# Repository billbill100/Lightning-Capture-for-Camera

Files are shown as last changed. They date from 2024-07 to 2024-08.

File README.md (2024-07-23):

# Lightning-Capture-for-Camera
Build a cheap device for your camera, to automatically photograph lightning as it happens.

Based on Arduino (but using a faster ESP32 processor), this clever device allows your camera to wait in standby, watching for lightning and take a photo the instant lightning is seen.

A dslr or mirrorless camera with a cable release socket will be required.

Using a battery powered processor, complete with built in-charger and off-the-shelf modules, the device can be quickly and easily built. There is no need to make or order complicated circuit boards (pcb).

A little soldering skill is required, as is a bit of computer skill to load the firmware onto the device, but there are how-to guides for each step and a user forum on Photrio.

There are two versions that can be built.
The full version includes an Oled display, with parameters that can be changed.
A basic model, with minimam components, that just works, using the default parameters.

Now the caveat. The device has been built & tested and it works great indoors. However there has yet to be thunderstorm to test it in the real world. As soon as a suitable storm blows through, I will be running outsideto fully test the device.

This is a new project, so documentation may change over the coming weeks.

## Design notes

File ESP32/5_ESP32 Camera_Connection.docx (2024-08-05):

GitHub repository where all documentation & code can be found. billbill100 (github.com) (https://github.com/billbill100)

Trigger Trap Timer & Lightning Capture

Camera Connections V1.1 18/07/2024

The opto-isolator board provides total electrical separation between the camera and the timer. One of the chips on the board is an ‘opto-isolator’. On one side is an LED, which lights when controlled by the ESP32. On the other side is a photo-resister., which sees this light & responds in kind. There is no electrical connection, the only thing passing across is light. This light is used to control the other side of the board, which connects to the camera.


Purchase the correct camera shutter release cable for your camera, to 3.5mm socket.

Canon use two different connectors, depending on the camera. A 2.5mm socket or bespoke Canon connector.

Nikon use three different camera connectors.

Canon & Nikon are the simplest of cables and a pre-made shutter release cable should be wired as such and should work without modification.

Some manufacturers use just two wires, but with added resisters, Fuji & Panasonic, for example. This makes the cable a little more complicated. Having not used such a camera or cable, I cannot say if pre-made cables have the additional resistors built in or not. For these cameras, some experimentation will be required & the use of a multimeter to test the cables.


To connect to the Trigger/ Lightning box 3.5mm jack plug,
Common Outer - Black
Focus to collar - Yellow
Shutter to Tip - Green

Below are links to useful web sites showing the connectors & pin-outs.

www.doc-diy.net :: camera remote release pinout list (https://www.doc-diy.net/photo/remote_pinout/)

DIY - Release Cable for Canon DSLRs (diyphotography.net) (https://www.diyphotography.net/release_cable_for_canon_dslr/)

Canon N3 Connector Pinout and Wiring : Martin Pot - Photography Blog (martybugs.net) (https://martybugs.net/blog/blog.cgi/gear/CanonN3Connector.html)

Panasonic Shutter Release Cable for Arduino Camera Control and Timelapse Ep 22 (youtube.com) (https://www.youtube.com/watch?v=_ZOJiIvAwBE&ab_channel=SunPixelVideo)

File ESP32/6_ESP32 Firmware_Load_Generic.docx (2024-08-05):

GitHub repository where all documentation & code can be found. billbill100 (github.com) (https://github.com/billbill100)

ESP32 generic firmware load. V1.0 23/07/2024

Download the code from the github page.
Go to the github page following the link above and then select the required project.
Click on the green <>Code button, which will allow you to download all of the files as a zip file.
Unzip (extract) the downloaded files.

Download the Flashing software.

A program called Flash Download Tool is required. It is included on the Github page, or can be downloaded from
Tools | Espressif Systems (https://www.espressif.com/en/support/download/other-tools)

Unzip (extract) the folder and put the files somewhere suitable on the computer. The software is stand-alone and does not need to be installed.

Checking the ESP32 USB driver.

The USB driver should have been installed, following the driver installation guide. To confirm, after connecting the ESP32 board, press Windows key + x and select Device Manager. Look for the COM ports and expand. The ESP module should be seen, as in this example on COM port 6, showing the CP2102 driver.

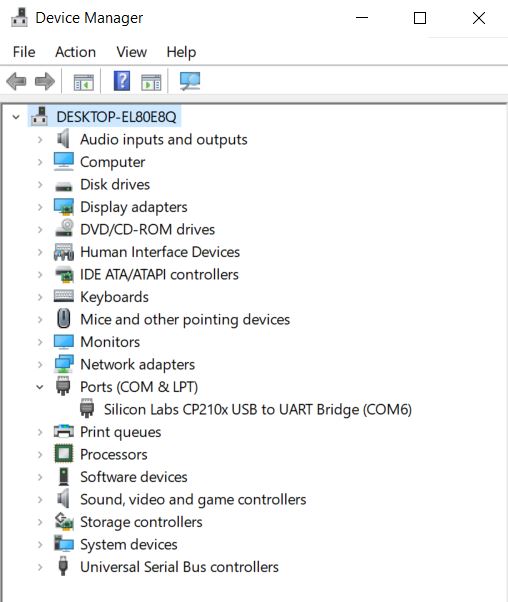
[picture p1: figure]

If the driver is missing, as shown on the screen below (Yellow Triangle) refer to the document Installing CP2102 Driver. Found in the github repository.

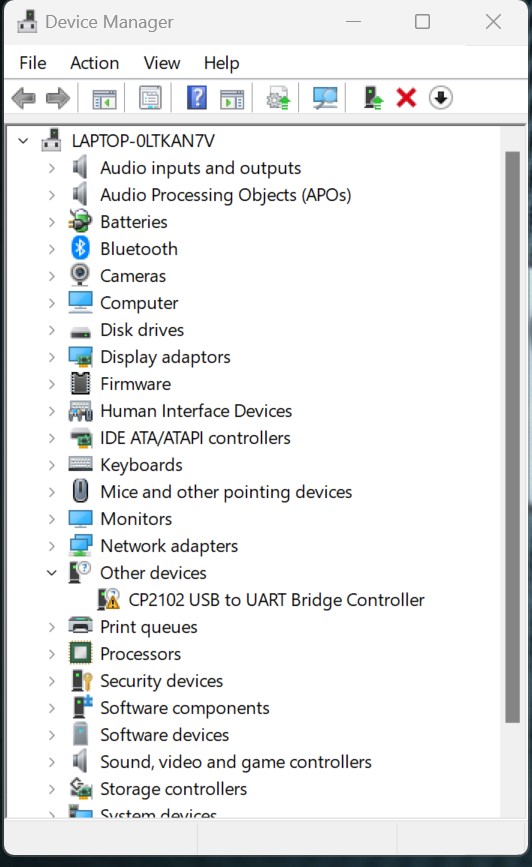
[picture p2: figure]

Flash the firmware to ESP32

Find the folder where the Flash Download Tool files were extracted to.

Launch the Flash Download Tool by double clicking on ‘flash_download_tool_3.9.5.exe’

Select ‘ESP32 from the drop-down box, as shown in the screenshot below and click ok.

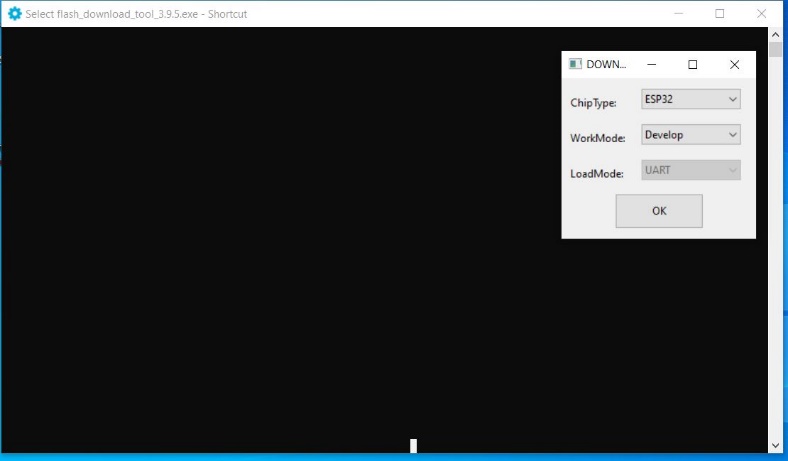
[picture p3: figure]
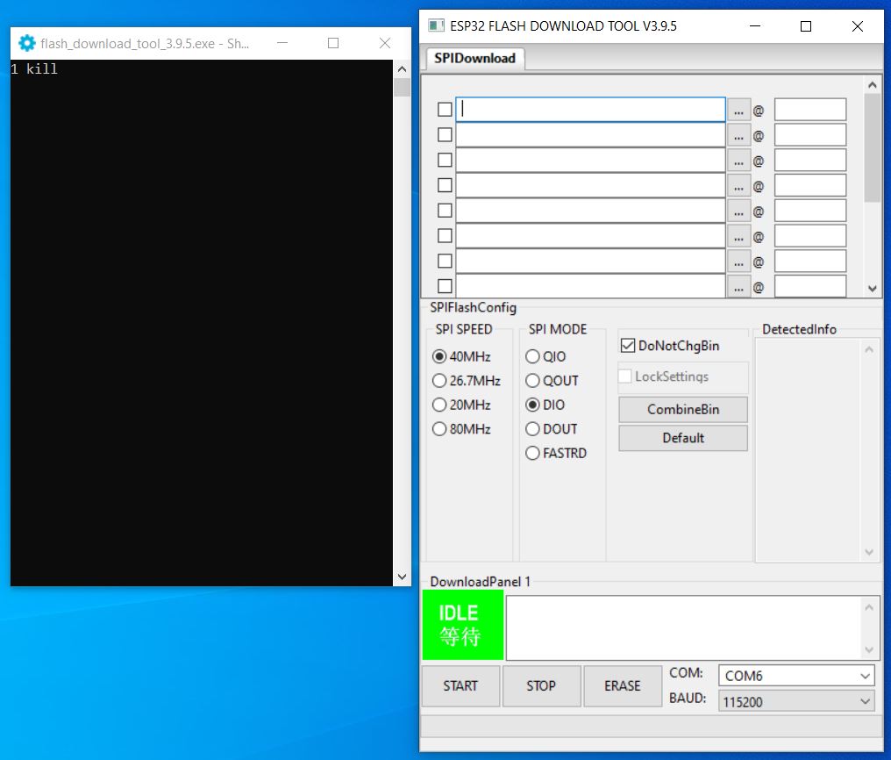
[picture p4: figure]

A screen like the below will appear and must now be populated. (The two windows can be moved as required)

Populate the values as follows

1) Click the three dots next to the top box, navigate to, and select the downloaded filename_x_x_x_x.ino.bootloader.bin. file. Do the same on the second line, selecting filename_x_x_x_.ino.partitions.bin and again for the third line filename_x_x_x_x.ino.bin If the files are selected correctly, the black window (5) will show each file name

(ensure the files are in the correct order)

2) Type 0x1000 into the top box, 0x8000 into the second and 0x10000 into the third.
3) Tick the three boxes next to the file names
4) Select the correct COM port from the drop-down box

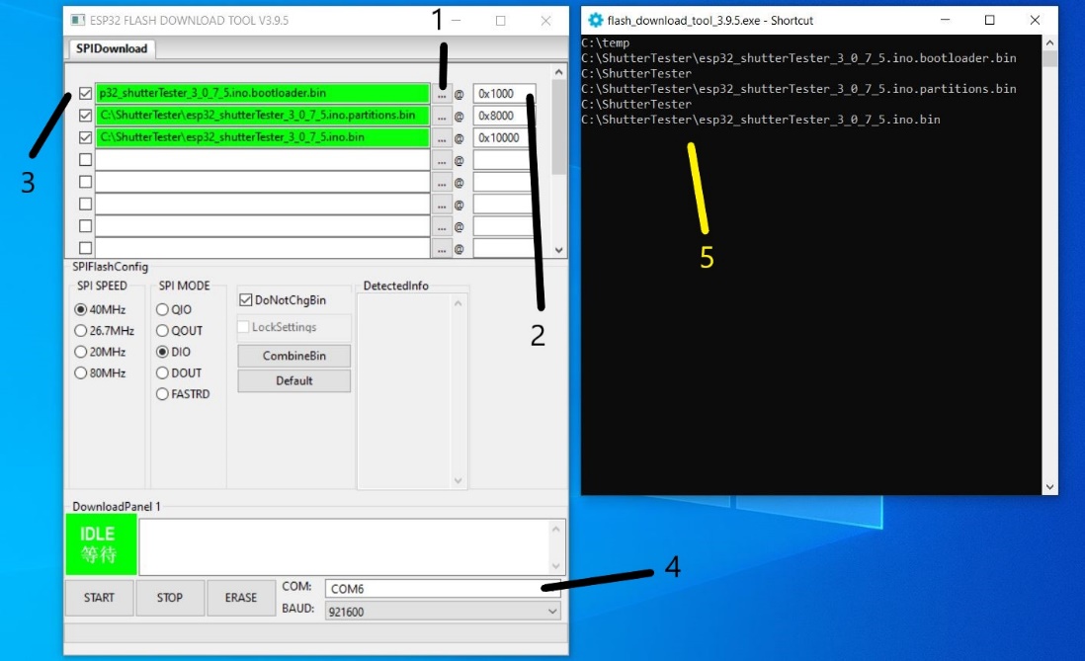
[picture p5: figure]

The file names and number boxes will be green, if the Flash Download Tool as found the files & is happy with the values.

Now press ‘Start’ at the bottom left of the box. The green ‘IDLE’ box will change to ‘SYNC’

A line of dots will appear on the black screen, Only if using the nodeMcu-32 board, press the Boot button on the ESP32 board for 3 seconds and then release. (The Lolinn board, as used in Lightning_Detector & Developing_Timer does not have the boot button)

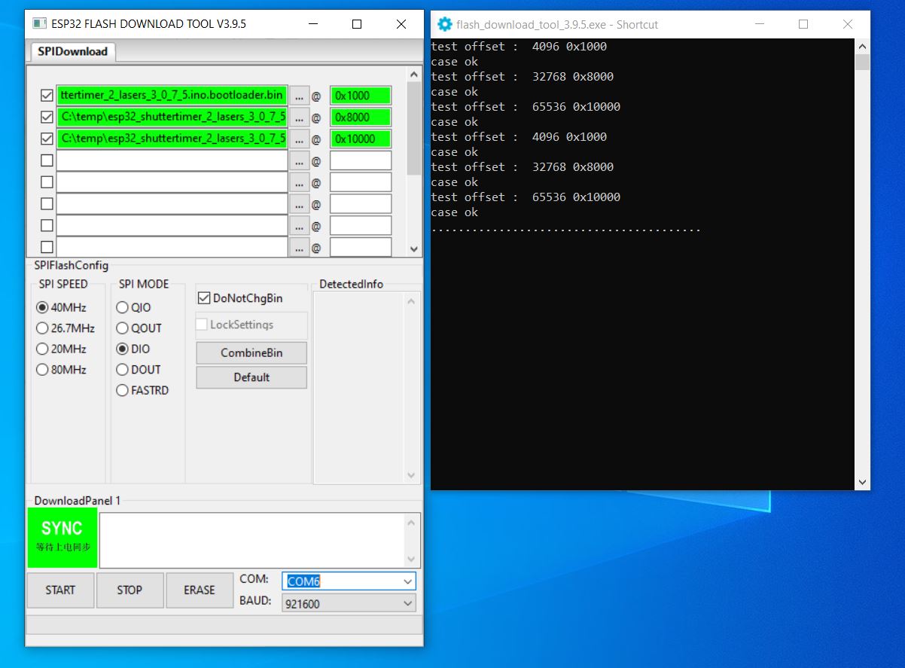
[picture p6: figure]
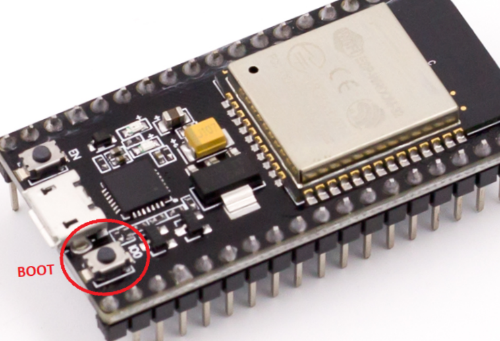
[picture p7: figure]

If successful, a screen, as below, will be seen. The Black screen will show the flashing to the device. A green progress bar blue box will appear in the other screen, then the green start button will change to a blue ‘FINISH’

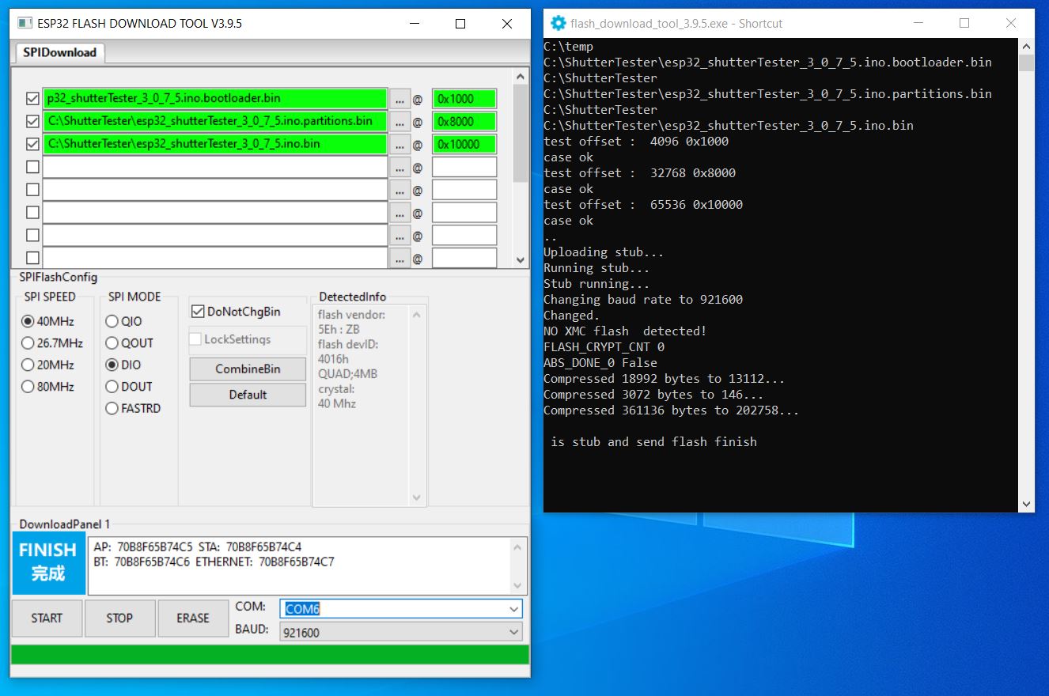
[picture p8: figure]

Note:- the flashed code will not start running until the Reset button has been pushed on the ESP32 board.

If problems occur, check the following:-

Remove & insert the USB cable into the computer. Windows, by default will make a sound indicating a USB device has been connected.

Open Device Manager and check the ESP32 board is shown. Removing & re-inserting the USB cable will make the ESP32 disappear & re-appear.

Ensure there is no yellow warning triangle by the COM port in Device Manager, indicating the device driver is not loaded.

Try changing the baud value to 115200 and try again.

If any of the file names or numbers did not turn green as they were selected & the black window report ‘case ok’, then there is an issue with the downloaded flash files, or the stored location on the computer.

Note:- this is a generic guide to loading firmware for the billblill projects.
The actual filenames will be different than those shown in the screen shots, but ensure the second part of the three file names, bootloader.bin partitions.bin and ino.bin are in the correct order as shown in the screenshots.

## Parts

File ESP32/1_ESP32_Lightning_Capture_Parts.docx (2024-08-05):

I would really be grateful if you start to build the Lightning Capture Device, that you go to the Photrio thread and say hi. Also please post photos of your completed project.
Please refer to the Photrio thread for further build help
Lightning Capture Device - Cheap - Simple & it works (photrio.com) (https://www.photrio.com/forum/threads/capture-lightning-device-cheap-simple-it-works.207958/)

GitHub repository where all documentation & code can be found. billbill100 (github.com) (https://github.com/billbill100)

Please refer to the Photrio thread for further build help

ESP32 Lightning Capture Parts V1.0 28 06 2024

Below are links to the parts required to make the ESP32 Lightning Capture device.

Links are valid now, but of course could become dead in the future.

Links are a guide only. Use a supplier in, or will post to your country.

Ordering from China either from eBay sellers or AliExpress, the parts will be much cheaper.

Note, often if buying from AliExpress, there is a free express shipping option, if buying parts over a set value.

One of two versions can be built, either fully featured with Oled and controls or a minimal version, The Schematic diagrams show the two versions.

ESP32 Lolin Wemos board

LOLIN D32 V1.0.0 - wifi+bluetooth board based ESP-32 esp32 ESP-WROOM-32 4MB FLASH Arduino MicroPython Compatible - AliExpress 502 (https://vi.aliexpress.com/item/1005006246561853.html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)

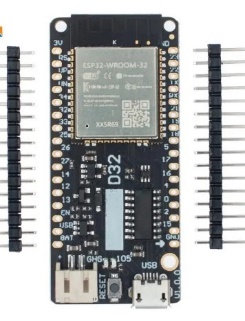
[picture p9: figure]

ESP32 prototype/breakout board (38 pin screw-terminal version)

New edition ESP32 Breakout Board for ESP32 WiFi Bluetooth Development Board NodeMCU-32S Lua 38Pin GPIO 1 into 2 Expansion Board - AliExpress 502 (https://vi.aliexpress.com/item/1005006100537758.html)

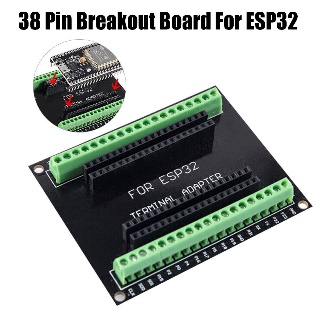
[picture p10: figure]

Dupont wires.

Get male to female ones if using the screw terminal prototype board.

It is suggested that two packs of 20cm and
two packs of 10cm wires are purchased.
This will allow for the exra Red & Black wires required.

Additionally a pack of 10cm male-male makes wiring to the opto-board easier. Alternate is to cut the F end from one Green, Yellow and Black wire.

Dupont Line 10cm 20cm Dupont Cables Male To Male Female To Female Male To FeMale Jumper Wire, for Arduino DIY Electronics KIT - AliExpress (https://www.aliexpress.com/item/1005006263457745.html?scm_id=1007.40050.354490.0&scm-url=1007.40050.354490.0)

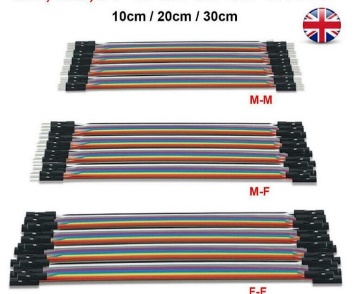
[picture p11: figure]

Rotary Encoder.
Ensure you purchase the one with blue pcb.

Rotating Potentiometer Knob Cap Digital Control Module Rotary Encoder Controller Switch 5V Diy Kit EC11 For Arduino PCB Board - AliExpress (https://www.aliexpress.com/item/1005006332290643.html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)

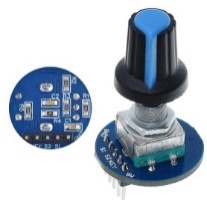
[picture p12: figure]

Project Box.
There are all sorts of shapes & sizes of project boxes. The 158 x 90 x 60 is a good size if using the breakout board.

Black Box Outdoor Waterproof Case Plastic Box Electronic Project Case Instrument Waterproof Junction Box Housing - AliExpress (https://www.aliexpress.com/item/1005005622148025.html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)

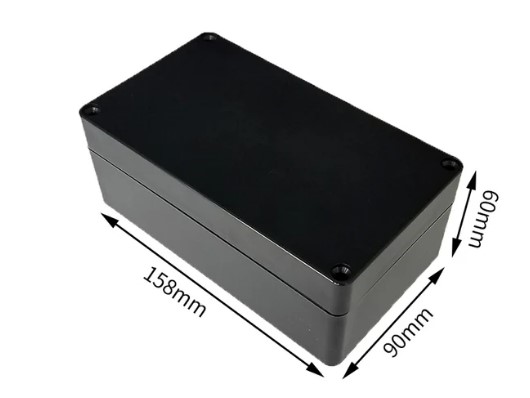
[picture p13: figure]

Oled screen
1.3” SH110X display

1.3" OLED module white/Blue color 128X64 1.3 inch OLED LCD LED Display Module 1.3" IIC I2C Communicate for arduino - AliExpress 502 (https://vi.aliexpress.com/item/1005006115101785.html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)

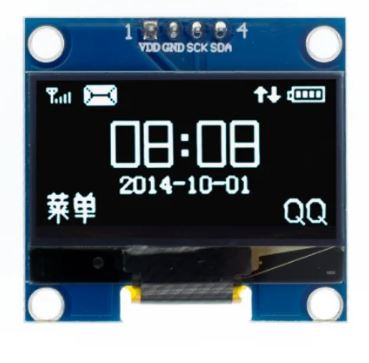
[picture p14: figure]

Opto isolation board
Two of these boards are required. Ensure you select the 3V-5V version when ordering.
Note:- The different versions seem to have got mixed up in china, so be prepared to change the resister on the board. Details in the documents.

1 Channel Way Optocoupler Isolation Module PC817 EL817 3V-5V 12V 24V Photoelectric Isolator Rail Holder PLC Drive Motor Board - AliExpress 502 (https://vi.aliexpress.com/item/1005003744306262.html)

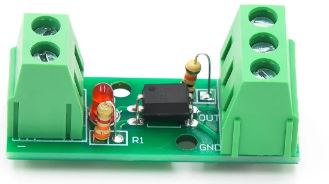
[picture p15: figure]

Resisters 27 Ohm
The resister on the opto board is too high for reliable working at 3 volts. It has also been found that the board sent, even if ordering the 3-5V version (which should have a 100 Ohm resister) may have a resister for working at 12 or 24 volts.
Simple solution is to replace it with a 27 Ohm resister to give correct operation at 3.3 volts.
100PCS Metal Film Resistor 1/4W 1% 100R 220R 1K 1.5K 2.2K 4.7K 10K 22K 47K 100K 100 220 1K5 2K2 4K7 Ohm Resistance 1R~22M - AliExpress 502 (https://vi.aliexpress.com/item/1005006427040577.html?mp=1)

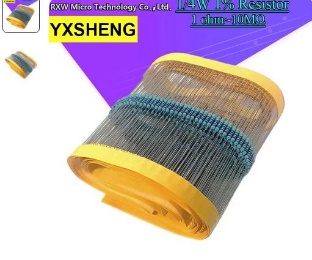
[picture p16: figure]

PCB mounting support (Optional).
20mm M3 & 10MM M3

The PCB in the prototype was mounted using wooden blocks. Whilst this does work, a neater solution is to use mounting spares designed for the purpose. 20mm for the breakout board & 10mm for the opto-isolator.

M2 M2.5 M3 M4 Nylon Motherboard Standoff PCB Support Circuit Board Column Rack Pillars Spacer Plastic Hex Screw Bolt and Nut Set - AliExpress 13 (https://vi.aliexpress.com/item/1005006038666758.html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)

Shutter Release Cable.
Get the correct one for your camera. An alternate is to buy a complete release & cut the button unit off.

2.5mm / 3.5mm Remote Shutter Release Cable Connecting Cord for Canon DSLR Camera As 3C C3 N3 Cable A as the cable of RS-80N3 - AliExpress 44 (https://vi.aliexpress.com/item/32851067494.html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)

2.5mm 3.5mm Remote Shutter Release Cable Connecting Cord for Nikon D850 D810 D700 D800 D300S D300 D4 D3X D2 As 1N N1 DC0 Cable B - AliExpress 44 (https://vi.aliexpress.com/item/32849320165.html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)

2.5 3.5 to Multi USB Remote Shutter Release Connecting Cable for Sony A7 A7S A7R II III IV V A6600 A6000 RX100 V as S2 Cable F2 - AliExpress (https://vi.aliexpress.com/item/32851067485.html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)

On/Off switch
There are hundreds of different types, pick one you like. Ensure it is ON/OFF and not momentary.

Push Button Switch Arduino|12mm Momentary Push Button Switches 3a 125vac 1.5a 250vac - 6pcs Set (aliexpress.com) (https://vi.aliexpress.com/item/4000164264475.html?mp=1)

Button

There are hundreds of different types, pick one you like. Ensure it is momentary.

(pre-soldered)

DaierTek 5PCS 12mm Momentary Push Button Switch On Off Mini Round Switch Waterproof PBS-33B 3A 125V AC with Pre-soldered Wire - AliExpress (https://www.aliexpress.com/item/1005005789195514.html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)


(require soldering)

6piece Mini 12mm Waterproof Momentary On/off Push Button Round Switch Pbs-33b Kit White Black Red Yellow Blue Green - AliExpress (https://www.aliexpress.com/item/1005006228814305.html)


Traffic Light LED (Optional)
These have built in resisters, thus simplifying use.

Mini 5V Traffic Light LED Display Module for Arduino Red Yellow Green 5mm LED RGB -Traffic Light for Traffic Light System Model - AliExpress 502 (https://vi.aliexpress.com/item/1005005568479247.html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)


Type C USB to Micro Adaptor (Optional)
The USB port will be recessed in the project box making connection a little fiddly. An adaptor or ‘port saver’ can be used to bring it outside of the box


Li-Po Battery (Optional, only for use with Lolin D32 board) With JST PH2.0 connector.
The prototype was built using the 1000mAh battery. A 2000mAh or 2500mAh battery will also work well. If using a different battery to the ones specified below, ensure they have the little pcb at the top, which gives under-voltage & over-current protection.
Note:- if ordering from China, delivery time maybe long as they are sent via ship, not air. Consider ordering from a supplier with stock in your country via Amazon or Ebay.

3.7V 1000mAh 3.7Wh Rechargeable Polymer Li Lithium Battery 523450 Lipo JST 2pin 1.5 Connector For Game Player LED GPS Car Camera - AliExpress 44 (https://vi.aliexpress.com/item/1005007364065757.html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)

3.7V 103450 2500mAh Lipo Polymer Lithium Rechargeable Battery 103450 battery For GPS navigator MP5 Speaker headset camera e-book - AliExpress 44 (https://vi.aliexpress.com/item/1005006274137007.html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)


Red & Black Pins require removal from plastic housing and swapping round.

Caution – There is no standard for the polarity of the battery connector. Check and double check the red & black wires are the correct way round on the battery connector, to match the Lolin processor board. If they are not, carefully lift the plastic locking tab on the connector, securing the pin & slide out. Do this for both pins, taking care not to let them touch. Then re-insert the correct way round. The batteries specified above have the connector pins the wrong way round and will need to be swapped.

Battery cable. (Optional)
Allows the battery wires to be easily extended without cutting..

2/5/10/20Pair Micro PH2 JST PH 2.0 PH2.0 2Pin Male Female Plug Jack Connector With Wire Cables 200mm - AliExpress 13 (https://vi.aliexpress.com/item/1005006623049916.html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)


Choc-block (Optional)
There are many 3V & 0V wires to be connected into a single terminal on the breakout board. A choc-bloc can be used to group all of the wires together & then just one wire from here to the breakout board.

Alternates are to solder them together, or use a joining block similar to the below,

10-75pcs Orange Universal Type Quick Plug-in Terminals,Electrical Equipment Connectors,Wire Connector Terminals,250V/32A - AliExpress (https://www.aliexpress.com/item/1005006271613810.html?scm_id=1007.40050.354490.0&scm-url=1007.40050.354490.0)


3.5mm socket.

Rather than hard wiring the remote camera cable, a socket on the box can be used. PJ-391 for the sockets.
10PCS 2.5 3.5MM Headphone Jack Audio Video Female Dual Channel Stereo Jack Jack Socket Stereo Solder Panel Mount PJ-210B PJ-392 - AliExpress (https://vi.aliexpress.com/item/1005006181883514.html?mp=1)

Glue Gun. (Optional)

Cheap glue gun, but surprisingly it works ok.

20W Hot Melt Glue Gun DIY Mini Household Industrial Guns Heat Temperature Thermo EU Electric Repair Tool Use 7mm Glue Sticks - AliExpress (https://www.aliexpress.com/item/1005005795878015.html)

Don’t forget the glue :o)

T TOVIA 60pcs/120pcs Hot Melt Glue Sticks 7mm Hot Glue Sticks Rod for Craft Album Repair Tools Hot Glue Gun Sticks - AliExpress (https://vi.aliexpress.com/item/1005005713317179.html?mp=1)

Soldering Iron Kit.

Cheap soldering iron kits are available on Aliexpress. I found the tips are very loose & the internet mod is to wrap a strip of aluminium cooking foil around the ceramic heater, to reduce the gap. Even then, they are really not good.
It is far better to buy a genuine branded product, Weller or Antex (not a cheap knock off).

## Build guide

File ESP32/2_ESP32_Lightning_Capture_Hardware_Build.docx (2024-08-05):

I would really be grateful if you start to build the Lightning Capture Device, that you go to the Photrio thread and say hi. Also please post photos of your completed project.
Please refer to the Photrio thread for further build help
Lightning Capture Device - Cheap - Simple & it works (photrio.com) (https://www.photrio.com/forum/threads/capture-lightning-device-cheap-simple-it-works.207958/)

GitHub repository where all documentation & code can be found. billbill100 (github.com) (https://github.com/billbill100)

Please refer to the Photrio thread for further build help

ESP32 Hardware Build V1.1 30/07/2024

Building the Lightning Capture should be relatively easy. Below are some hints & advise on the build.

It can be built as one of two versions.
a) Fully featured with Oled display and adjustable values
b) minimal design, without Oled or controls.

Ensure the correct firmware for your chosen version is used.

Refer to the ESP32 Wiring Guide schematic documents, for connections. Note. Schematics show a bare board, rather than it sitting in the breakout board.

The breakout board has 38 terminals, the ESP board only has 32. Mount the ESP32 so the spare 3 sockets on either side are to the rear. Do not use the legends printed on the breakout board as they will not be correct for the 32 pin ESP32 board.

All of the boards can be purchased from eBay, Amazon or AliExpress, which is by far the cheapest. Details of the parts required are detailed in the Parts List document

All of the modules are pre-built and do not require component soldering, however, the header pins on some modules, including the main ESP32 board require the header pins to be soldered.

Using DuPont jumper wires, the boards can be connected together. You will need one pack of 20cm and one pack of 10cm Dupont male-to-female wires.

Additionally, there are more Red and Black wires used, so one pack of each, 20cm Red & Black wires can be purchased to keep the colour coding correct

There are many 3.3V (Red)& GND (Black) power connections. These will not all fit into the breakout board screw-terminals. It will be necessary to connect them in groups with a choc-block or similar, then to the screw terminal.

When fully built & tested, consider using a little hot-glue on the connectors, to stop them working loose.

Ensure you pay particular attention to the polarity of the connections. The boards are clearly marked.

The OLED is marked Vcc and is connected to 3.3V. (Red wire) and GND, (Black wire). Note some displays have the polarity reversed. Check very carefully the legends printed on the board.

The Light Sensor board is marked VCC (3.3V) and GND. DO (digital Out) is the white wire.

The Traffic Light board is marked with the colours and also Vcc and Gnd.

The Rotary encoder is marked. Showing Vcc and 0V at either end of the row of pins, with the others clearly marked.

All of the parts (other than buttons with rear nut) were hot-glued into the project box. This works well for the OLED.
Wooden standoffs were cut to raise the breakout board above the buttons. Similarly, a wooden standoff was used for the opto-isolator. PCB standoff pillars can be used instead. Part description is in the parts document.

The photos are of the prototype and show a slightly different opto-isolator board. This required a resister to be added, to make it work at 3.3 volts. The opto-isolator board specified in the parts document also has to be modified by changing a resister, but being through-hole mounted, it is easier on this particular board.

The prototype has been tested with the Nikon Z8 and works perfectly using a standard 3.5mm to Nikon shutter release cable.
Refer to the camera connection guide for details of Nikon and other cameras.

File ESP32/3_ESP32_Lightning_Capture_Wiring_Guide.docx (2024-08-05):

I would really be grateful if you start to build the Lightning Capture Device, that you go to the Photrio thread and say hi. Also please post photos of your completed project.
Please refer to the Photrio thread for further build help
Lightning Capture Device - Cheap - Simple & it works (photrio.com) (https://www.photrio.com/forum/threads/capture-lightning-device-cheap-simple-it-works.207958/)

GitHub repository where all documentation & code can be found. billbill100 (github.com) (https://github.com/billbill100)

ESP32 Lightning Capture Wiring Guide V1.1 30/07/2024

Wiring of the modules is easily acclompished using Dupont wires. They come in a variety of lengths with terminals being male-male, female-female or male-female. Using a screw-terminal breakout board, male-female are most suitable, with a mix of 10 and 20cm lengths. Male-male can be used from breakout board to the opto-isolator if required.

There are limited 3.3V and 0V (or GND) screw terminals available. One solution is to gather the 3.3V wires together, cut off the connector and remove a small piece of the insulation. Terminate all of the wires into a choc-bloc and then just one wire from the choc-bloc will go to the screw-terminal on the breakout board. The same is then done with the 0V wires.

Do not use the GND terminal on the lower right of the Lolin D32 board. (it is an error on the board printing and is CMD, not GND)

Please be aware that the photos below are of the 32 pin Lolin D32 board and it only uses 32 of the 38 screw connections (the rear 3 on either side are not used) on the breakout board. The breakout board legends do not match that of the Lolin D32 board.

Please refer to the schematic for details of all connections and use them in conjunction with the photographs below.
Pin numbers refer to the ESP32 pin numbers as shown on the schematic. Not to be confussed wit normal ic pin number system.

Oled connections.
VCC - Red - Vcc
GND - Black - GND
SCK - Blue - 22
SDA - Purple - 24

Caution, some Oled modules have the Vcc and GND Reversed.
The screen-printed legends should be correct. In the photo just below the jumper wires, two soldered links can be shown, indicating how the board is wired for polarity.

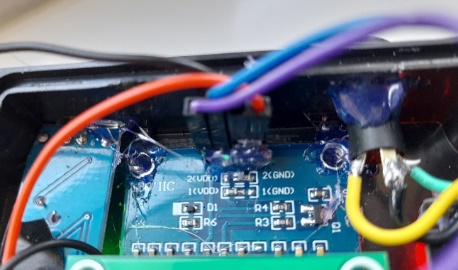
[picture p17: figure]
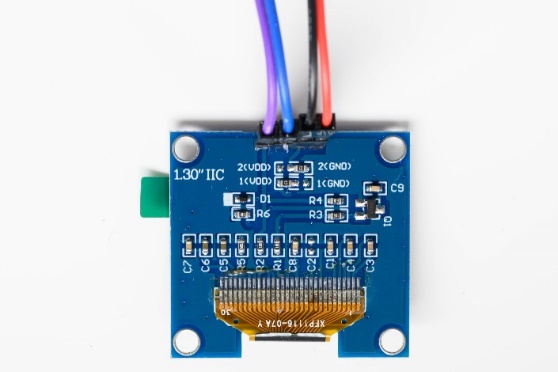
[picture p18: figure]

Encoder wiring.
3V - Red - 3V
Key - Purple - 26
S2 - Grey - 33
S1 - White - 25
GND - Black - GND

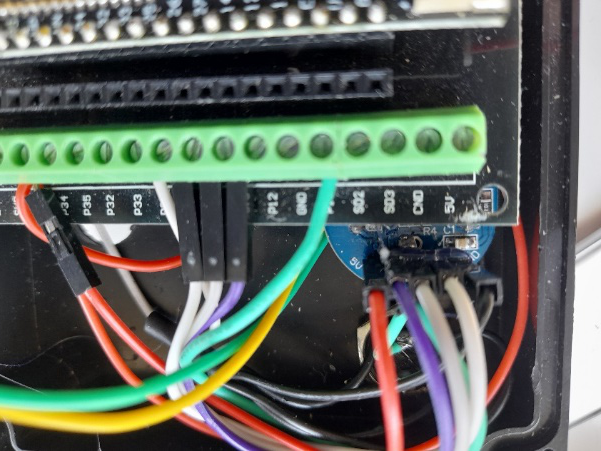
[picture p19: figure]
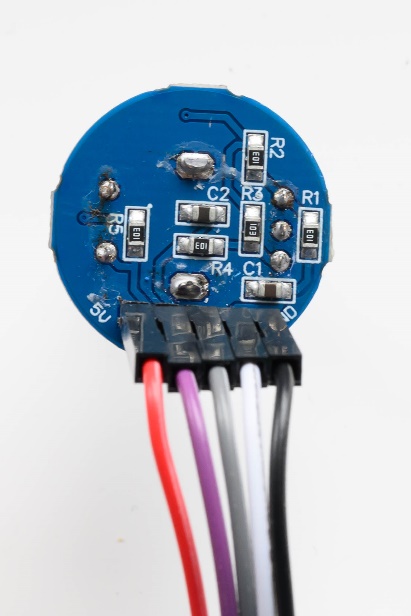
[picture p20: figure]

Opto-isolator
Although the bag clearly states 5V, the current limit resister is 470 Ohm, which is far too high to be used with 3.3 volts. They have sent a version that is for 12V. The resister must be removed and replaced with a 27 Ohm resister.

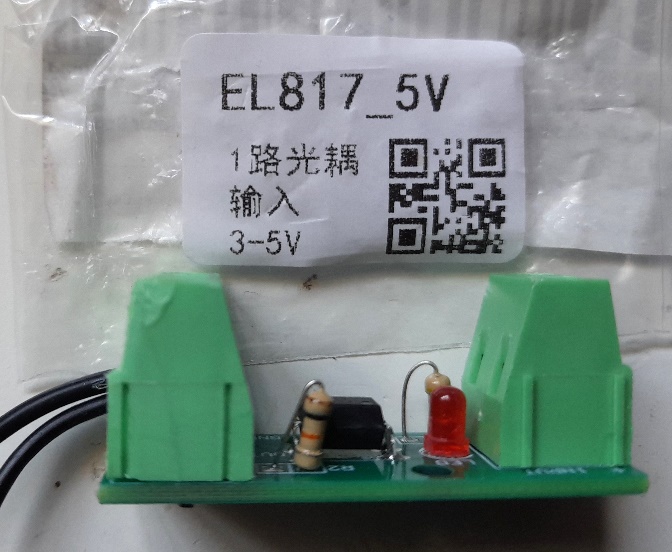
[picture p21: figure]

The yellow arrow points to the resister that must be changed to 27 Ohm resister

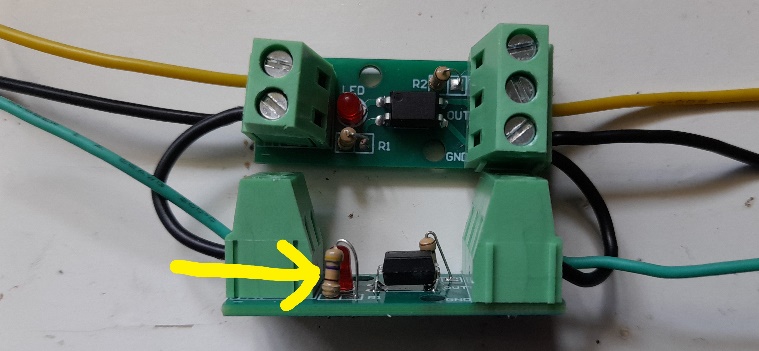
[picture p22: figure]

Otocouplers showing how they should be wired.
On the left, a 0V feed to each 0V input
Yellow wire to pin 19 of the ESP32
Green wire to pin 18 of the ESP32

On the right,
GND Out of Isolator – 3.5mm socket body
Yellow Out of Isolator – 3.5mm socket collar
Green Out of Isolator – 3.5mm socket tip

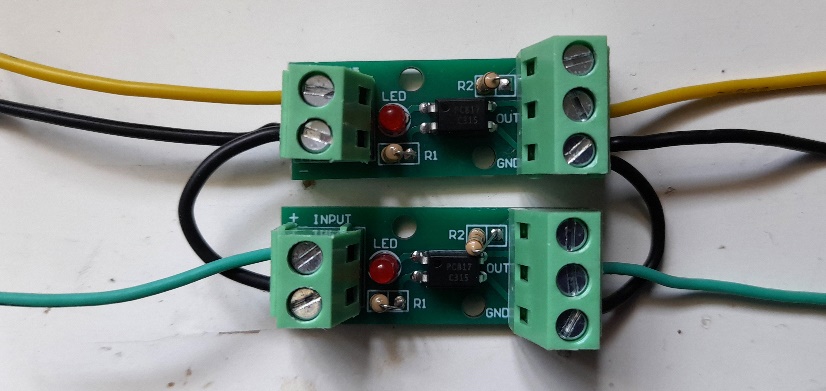
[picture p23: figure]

Button Wiring (no photo)
Button - Green - 12
Button - Black - GND

Traffic Lights
GND - Black - GND
Red - Red - 3V
Yellow - Yellow - 14
Green - Green - 17

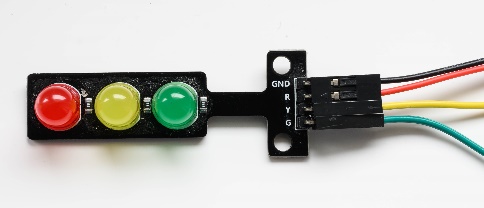
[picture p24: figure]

Shutter release socket
Body - Black - GND of Isolator Outputs
Collar – Yellow - Out of Isolator
Tip - Green - Out of Isolator

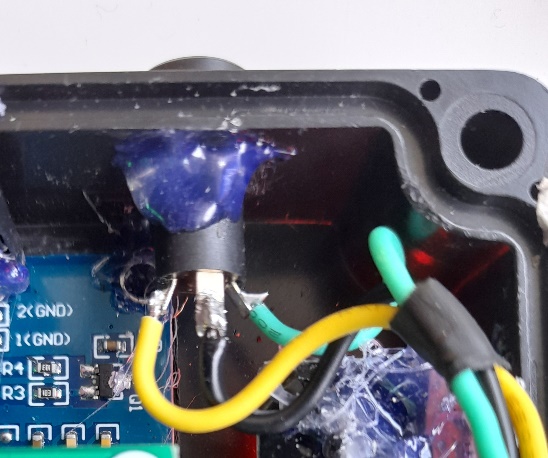
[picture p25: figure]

Completed wiring.

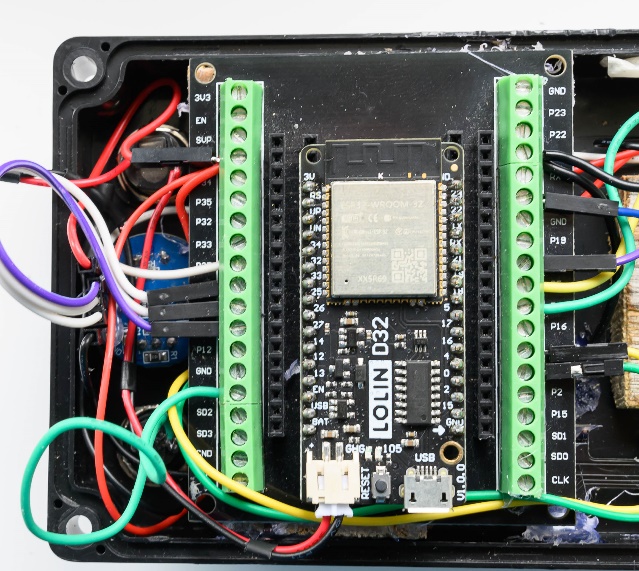
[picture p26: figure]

Note:- a different opto-isolator is shown in this photo.

A JST 2.0 plug and socket harness has also been used for the battery connection, which saves having to cut or extend the original battery wires.
With a male/female pair, solder together & insulate the two black bare ends.
Solder one red end to the on/off switch & the other red end to the other on/off switch terminal.
ENSURE YOU OBSEVER THE CORRECT POLARITY of connection to both the ESP board and the battery.

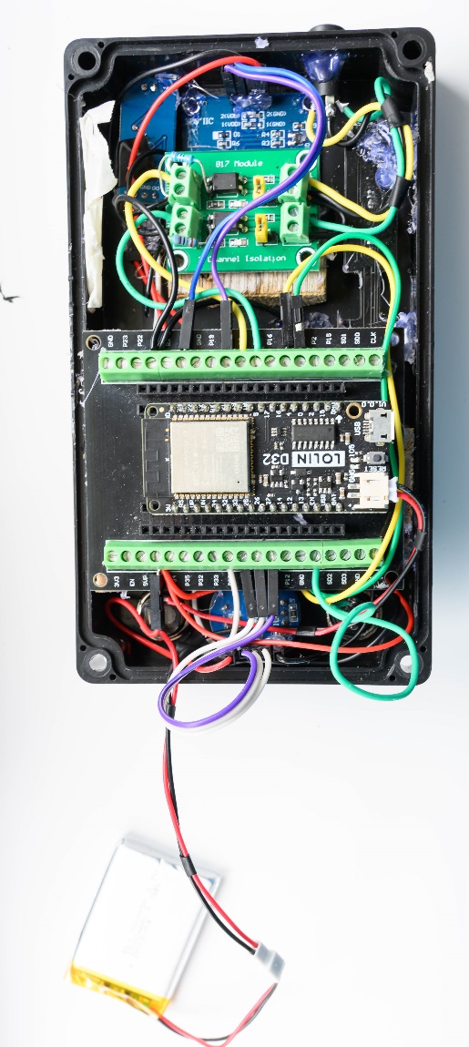
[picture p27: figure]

A very boring & rough looking project box.

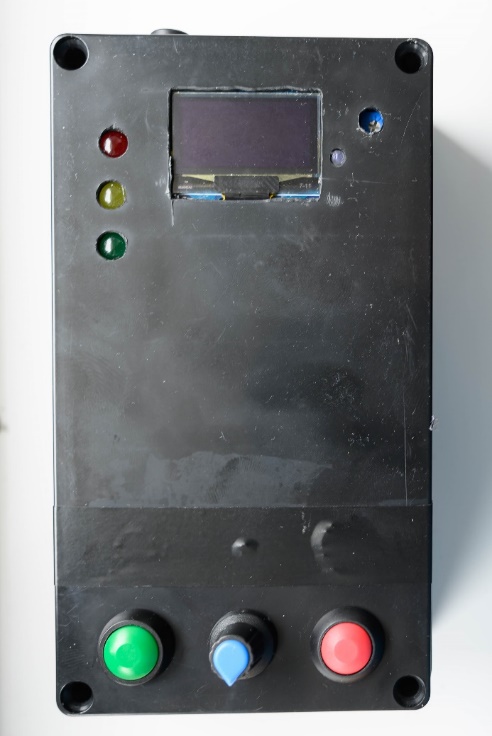
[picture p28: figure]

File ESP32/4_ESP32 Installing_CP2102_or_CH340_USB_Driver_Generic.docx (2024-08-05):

GitHub repository where all documentation & code can be found. billbill100 (github.com) (https://github.com/billbill100)

Installing CP2102 or CH340 USB Driver. V1.3 28/07/2024

Note:- The Lolin D32 board uses the CH340 driver
The NodeMCU32 board uses the CP2102 driver.

Depending on what project you are building and what ESP 32 board is used (Lolin D32 or NodeMCU32) will depend on which of the two drivers need to be installed on the computer.

The CP2102 device driver does not normally come pre-installed on Windows and has to be installed manually.
If using a ESP32 board with a different driver, Windows may or may not have a driver pre-loaded.

The CH340 driver will normally be installed on a Windows computer.
Follow the below to see if Windows has the CH340 driver. If not, skip to the end of this document for CH340 specific instructions

Connect the ESP32 board to the computer using a suitable USB cable.

Open Device Manager by pressing Windows Key + X and selecting ‘Device Manager’

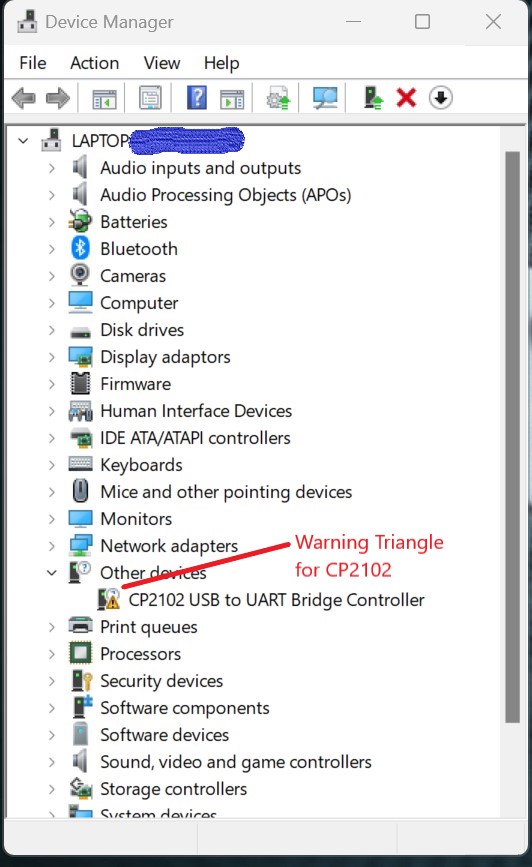
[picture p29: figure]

If you see a yellow ! triangle labelled CP2102, then drivers require installing.

Note:- the Ports (COM & LPT) may need expanding, to see the device.

Note:- if using a board with the CH340 USB device (Lolin D32) & the above is not showing it as working, skip to the end of this document for CH340 specific guidance.

Step 1,

Download the drivers from the link below.

Fow Windows users, select the top one, CP210x Universal Windows Driver

CP210x USB to UART Bridge VCP Drivers - Silicon Labs (silabs.com) (https://www.silabs.com/developers/usb-to-uart-bridge-vcp-drivers?tab=downloads)

Step 2,

Navigate to the downloaded file (most likely in Downloads directory) Highlight it by clicking once, then right-click and select ‘Extract All’ and accept the default directory.

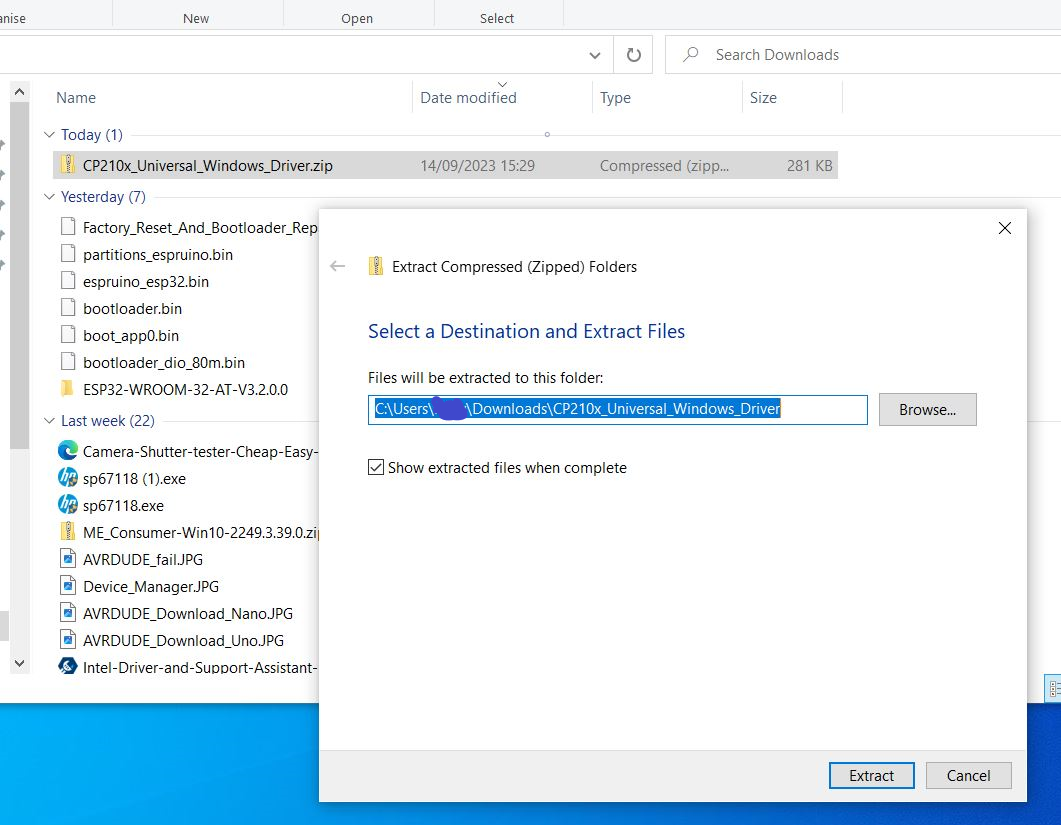
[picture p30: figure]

Step 3,

Go back to Device Manager and right-click on the Yellow ! Triangle
select ‘Update Driver’ and then ‘Browse my computer for drivers’

Click ‘Browse’ and navigate to the Downloads folder, find and click on the folder that was previously downloaded & extracted.

Click ‘Ok’ and then ‘Next; in the previous box and the drivers should be installed.

A computer re-start will be required to complete installation.

CH340 Specific Instructions.

If the CH340 driver is not loaded & Windows is not showing an option to automatically install it, follow the link below for a video guide.

How to Install CH340 Drivers - SparkFun Learn (https://learn.sparkfun.com/tutorials/how-to-install-ch340-drivers/all)

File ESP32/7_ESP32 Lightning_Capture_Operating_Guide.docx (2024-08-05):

I would really be grateful if you start to build the Lightning Capture Device, that you go to the Photrio thread and say hi. Also please post photos of your completed project.
Please refer to the Photrio thread for further build help
Lightning Capture Device - Cheap - Simple & it works (photrio.com) (https://www.photrio.com/forum/threads/capture-lightning-device-cheap-simple-it-works.207958/)

GitHub repository where all documentation & code can be found. billbill100 (github.com) (https://github.com/billbill100)

V1.1 30/07/2024

Lightning Capture Operating Instructions

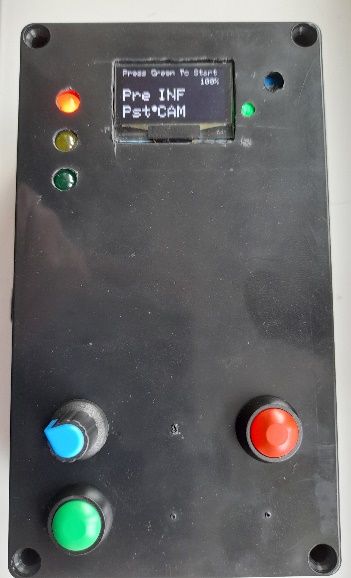
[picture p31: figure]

Buttons

Blue button. Each time this button is pressed, the red marker will move to the next parameter.

Blue knob. Turning the knob will change the parameter.

Green. Starts the Lightning Capture.

Blue button. Ends Lightning Capture & returns to parameter screen.

LEDs

Red LED. Power.

Yellow LED. Half Press Shutter – watching for Lightning.

Green LED. Full Press Shutter – taking a photo.

Light Sensor

Blue/White screw. Adjusts sensitivity of Light Sensor.

Green LED. Light Seen

On-Screen Parameters

Pre.
Sets how long the camera will wait with shutter ‘half-press’ watching for lightning.

Pst (post)
How long the shutter will stay open for, when triggered by lightning.

Battery
Alternates between voltage and percentage. Only show whilst in parameter menu

Note:-
The two parameters above are normally set to INF (infinite) and Cam (camera settings). However, they can be changed from 1/1000s to 480 seconds. See ‘Fun & Games’ below.

Basic operation – Full version
The Light Sensor must be adjusted using a small screwdriver, so that in ambient light, the green led on the board just turns off. Note, there is a secondary green power light on the board, which is always on.

The Lightning Capture is connected to the camera using a suitable shutter release cable.

The camera must be in manual mode, including focus & iso.
Focus the camera either at infinity or at a suitable distance, if including foreground. Then ensure auto-focus is turned off.

Set the camera iso, shutter speed and aperture as appropriate. This will involve a little trial and error and setting will depend on ambient light and if you are being creative with light-painting or fill flash for the foreground.

Press the Green start button & the camera will act the same way as half-pressing the shutter button and the Yellow LED will illuminate (ensure LEDs will not fog the photo)

When lightning is seen, the shutter will be fully pressed and the Green LED illuminate.

The camera will now take a photo, for the duration the camera shutter speed has been set to.

Note:- The Lightning Capture box has no idea of the camera settings, so after seeing lightning, it will immediately release the shutter and half-press again, watching for the next lightning strike, but the camera settings take priority.

To stop lightning-capture, press the blue knob. The unit will close the shutter and return to the initial menu screen.

Basic operation – Minimal version
The Light Sensor must be adjusted using a small screwdriver, so that in ambient light, the green led on the board just turns off. Note, there is a secondary green power light on the board, which is always on.

The Lightning Capture is connected to the camera using a suitable shutter release cable.

The camera must be in manual mode, including focus & iso.
Focus the camera either at infinity or at a suitable distance, if including foreground. Then ensure auto-focus is turned off.

Set the camera iso, shutter speed and aperture as appropriate. This will involve a little trial and error and setting will depend on ambient light and if you are being creative with light-painting or fill flash for the foreground.

When powering on, the unit goes straight into Lightning-capture mode and the Yellow LED will illuminate (ensure LEDs will not fog the photo) (There is no Green button to start)

When lightning is seen, the shutter will be fully pressed and the Green LED illuminate.

The camera will now take a photo, for the duration the camera shutter speed has been set to.

Note:- The Lightning Capture box has no idea of the camera settings, so after seeing lightning, it will immediately release the shutter and half-press again, watching for the next lightning strike, but the camera settings take priority.

To stop lightning-capture, turn the unit off.

Fun & Games with the Full version.
The ‘pre’ parameter specifies how long the Lightning Capture will wait for lightning. The default is infinity, however this can be set between infinity, 480 seconds to 1/1000s. At the end of this time, a photo will be taken, even if lightning is not seen. This can be used as an intervalometer, or if the camera has pre-capture & is set to do so, one can save the pre-capture photographs.

The ’Pst’ or Post parameter sets how long the shutter stays open for. Normally this is set on the camera, however if the camera is set to Bulb mode, then the Lightning Capture can control the exposure time.

The camera of course, need not be set to Manual or Bulb mode. For example, it could be set to continuous shooting at 1/60s. By setting the Pst to 5s, one would get a burst of 1/60s stills for 5 seconds.

This could be used to take a series of shorter photographs once lightning is seen, for manual blending & editing.

For cameras with pre-capture, this can be used to capture the pre and post lightning (removing latency issue) by setting the camera up for pre-capture. When lightning is seen, the pre-captured images will be saved and a series of post-images will be taken depending on the ‘Pst’ setting.

Note:- The Lightning Capture has a minimum shutter press length of 1/1000s. It is unlikely a faster shutter speed would be required, however if the camera is set to something like 1/8000s, there may be multiple 1/8000s images taken, as the camera will ‘see’ the shutter is pressed for 1/1000s.

General Notes
Shutter latency is the time from when the shutter is pressed to the time the camera has lifted the mirror & opened the shutter. This can be many milliseconds. The Lightning capture also has latency between lightning being seen and it operating the camera. This cannot be helped. All electronics will have some latency.

For this reason, the Lightning Capture has been coded to minimise latency, with priority given to looking for lightning and operating the shutter, before updating the display. This is also why the camera sits in ‘half-press’ mode waiting for lightning.

Caveat.
The Lightning Capture has been built & tested and all works well. The one thing that has not been tested is photographing actual lightning! It is just a waiting game until a suitable storm comes along.

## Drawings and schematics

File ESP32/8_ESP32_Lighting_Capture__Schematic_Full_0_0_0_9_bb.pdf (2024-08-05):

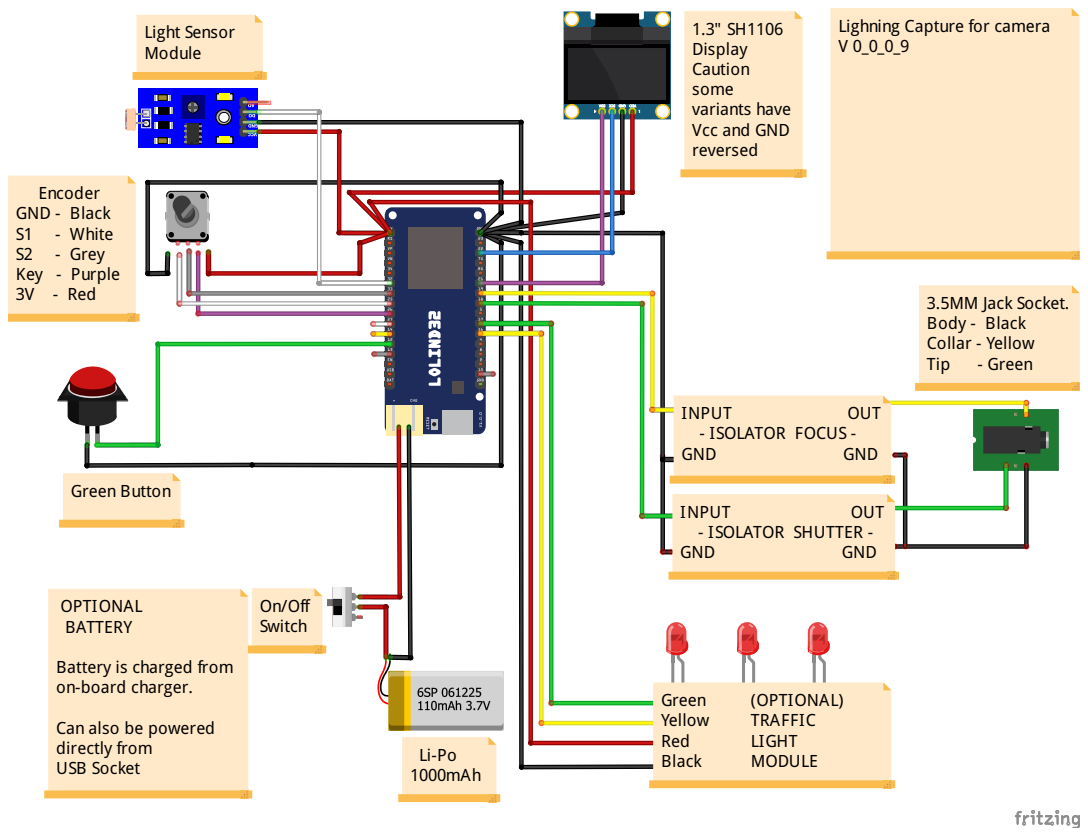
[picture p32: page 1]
INPUT; OUT; - ISOLATOR SHUTTER -; GND; - ISOLATOR FOCUS -; Li-Po 1000mAh; OPTIONAL BATTERY; Green; (OPTIONAL); Yellow; TRAFFIC; Red; LIGHT; Black; MODULE; On/Off Switch; Encoder GND - Black; - White; - Grey; Key - Purple 3V - Red; Green Button; 3.5MM Jack Socket. Body - Black Collar - Yellow; Tip; - Green; 1.3" SH1106 Display Caution some variants have Vcc and GND reversed; Light Sensor Module

Lighning Capture for camera

Battery is charged from
on-board charger.

Can also be powered
directly from
USB Socket

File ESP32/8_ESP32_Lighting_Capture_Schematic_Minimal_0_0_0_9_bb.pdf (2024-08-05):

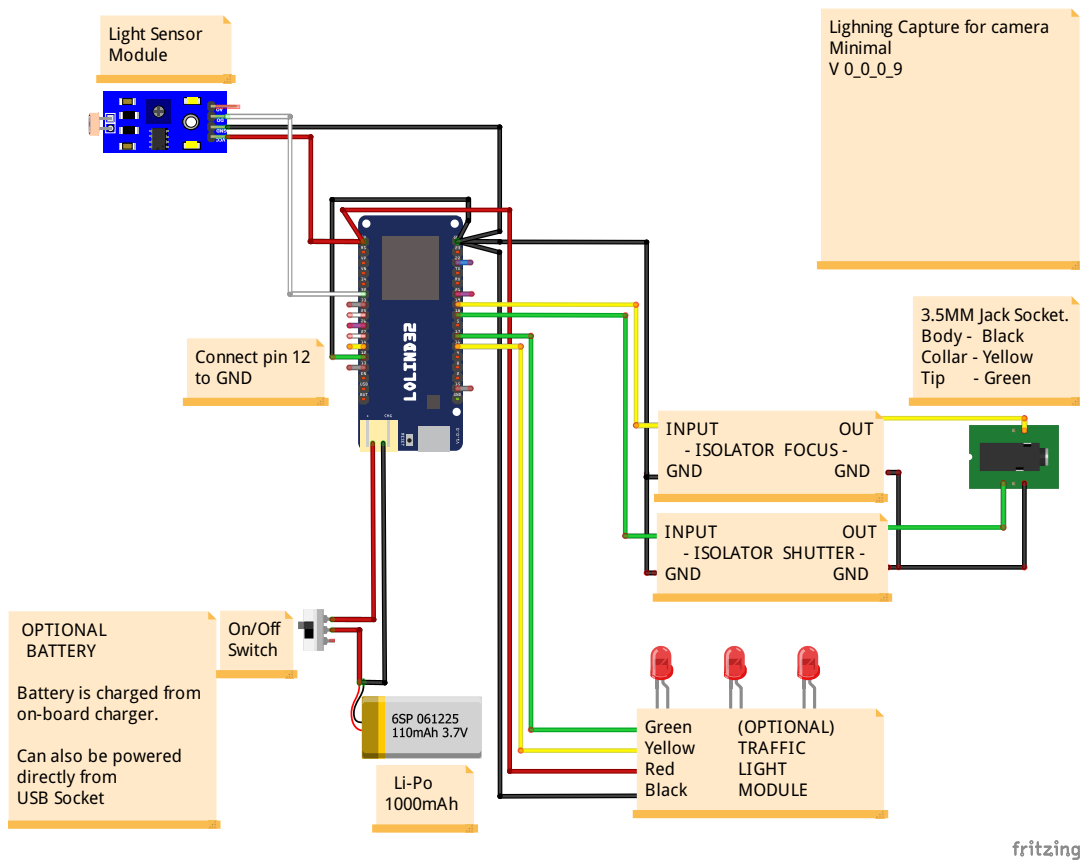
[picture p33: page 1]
INPUT; OUT; - ISOLATOR SHUTTER -; GND; - ISOLATOR FOCUS -; Li-Po 1000mAh; OPTIONAL BATTERY; Green; (OPTIONAL); Yellow; TRAFFIC; Red; LIGHT; Black; MODULE; On/Off Switch; 3.5MM Jack Socket. Body - Black Collar - Yellow; Tip; - Green; Light Sensor Module; Connect pin 12 to GND

Lighning Capture for camera
Minimal

Battery is charged from
on-board charger.

Can also be powered
directly from
USB Socket
